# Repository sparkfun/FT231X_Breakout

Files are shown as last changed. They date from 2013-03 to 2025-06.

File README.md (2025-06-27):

FT231X Breakout
========================

[FT231X Breakout  
*FT231X Breakout (BOB-11736)*](https://www.sparkfun.com/products/11736)

This is a simple breakout board for the FTDI FT231X. A **USB to serial UART** interface with full modem control. The board has a micro USB connector, and other support circuitry to get the IC quickly up-and-running.

Repository Contents
-------------------

* **/hardware** - PCB design files (created with Eagle 6.1.0)
* **/Production Files** - Test bed files and production panel files

License Information
-------------------

All contents of this repository are released under [Creative Commons Share-alike 3.0](http://creativecommons.org/licenses/by-sa/3.0/).

Author
------

Jim Lindblom, [SparkFun Electronics](https://www.sparkfun.com)

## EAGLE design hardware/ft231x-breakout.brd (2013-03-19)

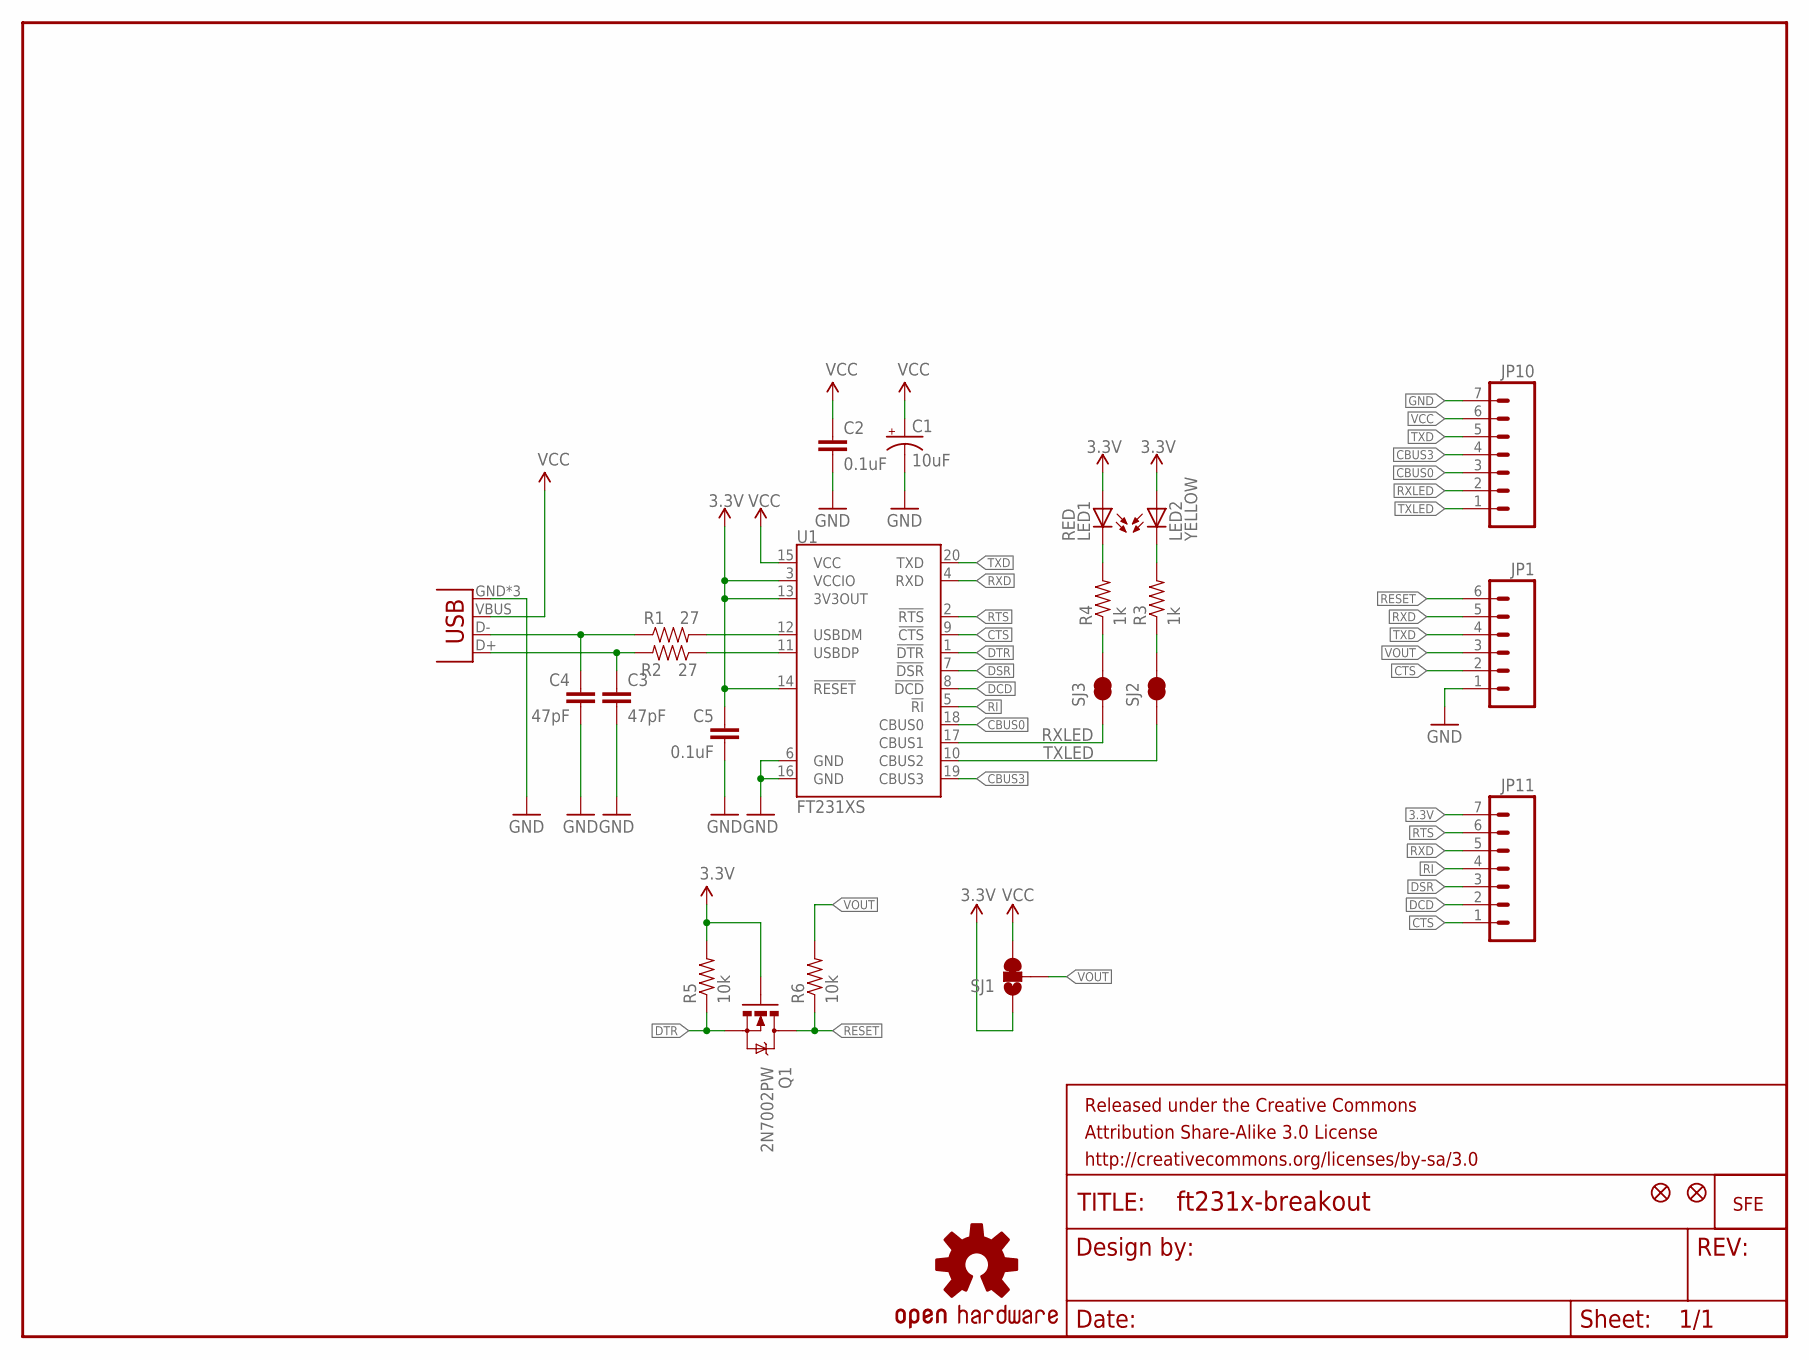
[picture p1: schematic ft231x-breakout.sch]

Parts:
C1: 10uF; EIA3216
C2, C5: 0.1uF; 0402-CAP
C3, C4: 47pF; 0402-CAP
FRAME1: FRAME-LETTER; CREATIVE_COMMONS
JP1: M06SIP-NS; 1X06_NS
JP2: LOGO-SFENW2; SFE-NEW-WEB
JP3, JP4: FIDUCIALUFIDUCIAL; MICRO-FIDUCIAL
JP10, JP11: M07NS; 1X07_NS
LED1: RED; LED-0603
LED2: YELLOW; LED-0603
Q1: 2N7002PW; SOT323
R1, R2: 27; 0402-RES
R3, R4: 1k; 0402-RES
R5, R6: 10k; 0402-RES
SJ1: SOLDERJUMPER_2WAYS; SJ_3
SJ2: TXLED; SJ_2S-TRACE
SJ3: RXLED; SJ_2S-TRACE
U1: FT231XS; SSOP20_L
U$1: OSHW-LOGOS; OSHW-LOGO-S
X1: USB-MICROB

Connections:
3.3V: C5.1, JP11.7, LED1.A, LED2.A, Q1.1 (G), R5.2, SJ1.1, U1.3 (VCCIO), U1.13 (3V3OUT), U1.14 (!RESET)
CBUS0: JP10.3, U1.18 (CBUS0)
CBUS3: JP10.4, U1.19 (CBUS3)
CTS: JP1.2, JP11.1, U1.9 (!CTS)
DCD: JP11.2, U1.8 (!DCD)
DSR: JP11.3, U1.7 (!DSR)
DTR: Q1.2 (S), R5.1, U1.1 (!DTR)
GND: C1.C (-), C2.2, C3.2, C4.2, C5.2, JP1.1, JP10.7, U1.6 (GND), U1.16 (GND), X1.GND, X1.MT1 (GND), X1.MT2 (GND)
unnamed: R1.2, U1.12 (USBDM)
unnamed: R2.1, U1.11 (USBDP)
unnamed: C3.1, R2.2, X1.D+
unnamed: C4.1, R1.1, X1.D-
unnamed: LED2.C, R3.2
unnamed: LED1.C, R4.2
unnamed: R3.1, SJ2.2
unnamed: R4.1, SJ3.2
RESET: JP1.6, Q1.3 (D), R6.1
RI: JP11.4, U1.5 (!RI)
RTS: JP11.6, U1.2 (!RTS)
RXD: JP1.5, JP11.5, U1.4 (RXD)
RXLED: JP10.2, SJ3.1, U1.17 (CBUS1)
TXD: JP1.4, JP10.5, U1.20 (TXD)
TXLED: JP10.1, SJ2.1, U1.10 (CBUS2)
VCC: C1.A (+), C2.1, JP10.6, SJ1.3, U1.15 (VCC), X1.VBUS
VOUT: JP1.3, R6.2, SJ1.2

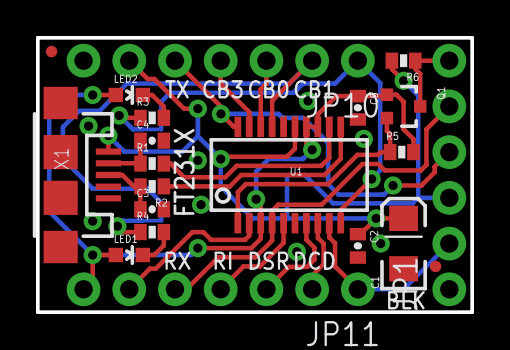
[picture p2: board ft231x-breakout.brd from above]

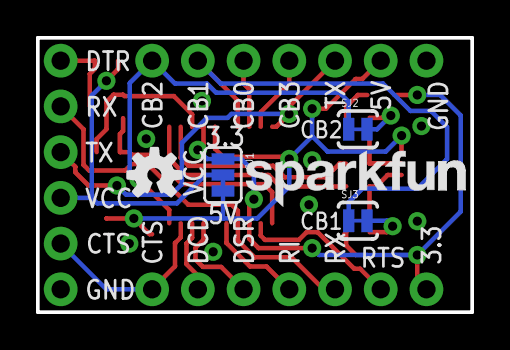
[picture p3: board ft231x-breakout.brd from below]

Board: 2 copper layers, 24.1 x 15.2 mm, 27 parts (5 on the bottom side), 25 nets.

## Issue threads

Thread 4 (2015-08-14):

review for v11 protos

lewispg228, 2015-08-14:
1) Is 'Revised by:' and 'reviser name' included? [NO]
comment: Kade didn't want his name on this, that's okay i guess

2) Do all VCC connections use the VCC symbol (oriented upward)? [NO]
comment: 3.3V net off of JP11 should be a supply symbol

3) Does every part have a NAME and VALUE (with proper prefix and no '$')? [NO]
comment: USBAB connector should be a "JP"

4) Are vias tented correctly? [YES]
comment: Yes, but the bstop by the jumpers needs to be scooted over the jumper traces (or removed)

5) Is the LED color standard followed? (red for power, blue for STAT, green for TX, yellow for RX) [NO]
comment: TX LED should be green, RX led should be yellow

6) Are any traces exposed?  [YES]
comment: Strange bstop near jumpers, also mentioned in via/stop check issue

7) Is the designer name included in tDocu? [YES]
comment: jim lidblom is overlapping the designed by text

SFE-KADE, 2015-08-14:
1.) Yea I don't want my name on this. It's still Patrick's rev.
2.) Fixed
3.) Fixed. In doing this I noticed there was a symbol update that now includes the shielding as a pin connection. In keeping with the Intel standard for EMI mitigation I connected it directly to ground. This tracks with some other designs on the storefront as well.
4.) Fixed (removed)
5.) Since this is a DFM rev only I'm leaving the LED colors as is as to keep this as the same SKU, same BOM, etc. Changes to LED colors can be done when this entire product line is overhauled.
6.) Fixed (removed)
7.) Fixed

lewispg228, 2015-08-14:
Thanks Kade. It looks like the strange bstop lines are still on there.

SFE-KADE, 2015-08-14:
Got some of it but not all of it that last teim. Fixed now.

lewispg228, 2015-08-17:
right on. looks good. thanks.

Closed 2015-08-14.

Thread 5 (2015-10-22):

v11 (again) for proto

lewispg228, 2015-10-22:
1) Is there a correct version number in the copper? [YES]
comment: Yes, but would you please slide it to the board edge and thanks

2) Are measurements included for outer dimension and standoffs (Eagle layer 47)? [YES]
comment: Way to go remembering to update measures rock on

3) Please shift board so that the bottom left of the dimension is at 0,0. Thanks!

SFE-KADE, 2015-10-22:
Right on. Should we add items 1 and 3 to the checklist officially?

lewispg228, 2015-10-22:
thanks and will do (I'll run it by the committee tomorrow, but I'm confident it will be approved).

Closed 2015-10-22.

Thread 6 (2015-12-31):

Checklist for v11 for Reds (again) - BOM/ prod id problem

lewispg228, 2015-12-31:
Looks like R3, R4 and JP1 have different prod ids than what I'm seeing in sparkle. Could you please check this out, and make it all consistent. Thanks!

SFE-KADE, 2016-01-04:
Fixed. Give it a second look.

lewispg228, 2016-01-04:
Looks Good. And thanks for updating the library too!

Closed 2016-01-04.

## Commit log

2013-02-15 Initial hardware commit (v01)
    [ft231x-breakout-v01.csv, ft231x-breakout.brd, ft231x-breakout.sch]
2013-02-18 Updated micro USB connector
    This is Pete's micro-USB package, which has two more pads under the
    connector to solidify the physical connection.
    [ft231x-breakout.brd, ft231x-breakout.sch]
2013-02-18 Removing BOM
    [ft231x-breakout-v01.csv]
2013-03-15 Silkscreen fixes: no-silk headers, moved labels
    [ft231x-breakout.brd, ft231x-breakout.sch]
2013-03-18 Added fiducials, minor silkscreen changes.
    [ft231x-breakout.brd, ft231x-breakout.sch]
2013-03-19 Production readiness
    Created panel of boards. Adjusted fiducial position.
    [ft231x-breakout.brd]

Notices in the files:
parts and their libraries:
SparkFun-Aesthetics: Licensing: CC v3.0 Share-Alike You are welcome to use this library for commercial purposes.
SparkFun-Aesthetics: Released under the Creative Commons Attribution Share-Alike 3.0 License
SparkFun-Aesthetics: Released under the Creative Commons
